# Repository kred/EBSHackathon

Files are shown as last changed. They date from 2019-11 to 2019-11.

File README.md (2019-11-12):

# EBSHackathon
Hackathon trophy model and firmware for Mentor Graphics Katowice hackathon event. Trophy is highly hackable!

## 3D model and 3D print
Trophy was designed in Autodesk Fusion 360. Step and stl models are located in the **Model** directory.
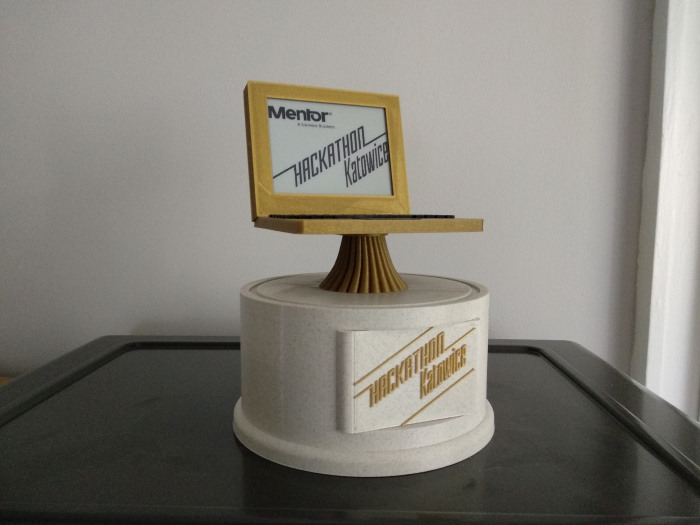
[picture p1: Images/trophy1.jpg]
Trophy

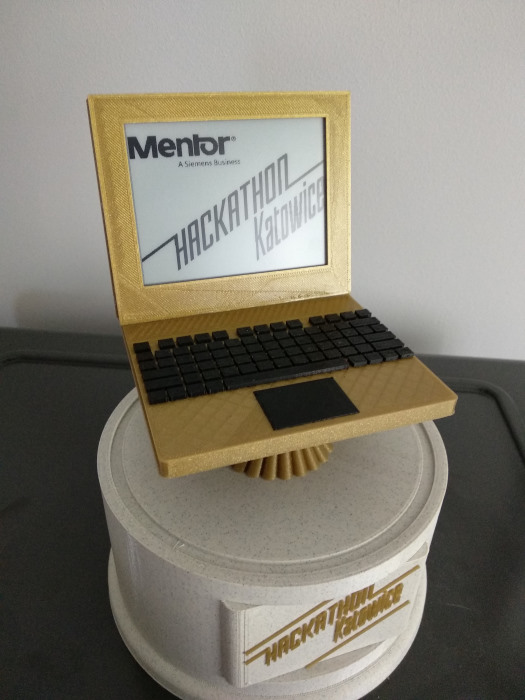
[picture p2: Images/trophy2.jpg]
Trophy

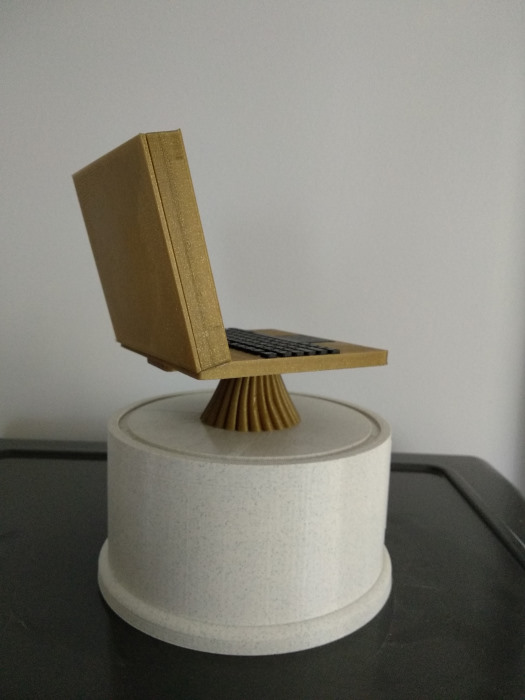
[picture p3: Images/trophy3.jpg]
Trophy

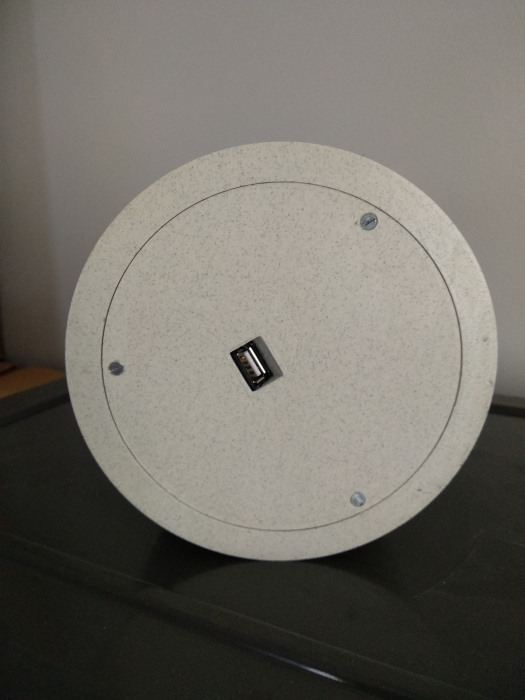
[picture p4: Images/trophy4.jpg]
Trophy


Front plate (where gold Hackathon Katowice label is shown) is detachable, so you may design new one and replace it. Notebook is glued to the foot and foot is connected to the base by three M3 screws. Notebook backplate is detachable, but currently is hot-glued to the display.
At the bottom of the base, there is circular cover fixed by three M3 screws. There is USB powerbank and ESP8266 inside. Power bank can be charged by external USB-A socket (power only - data signals are unconnected).

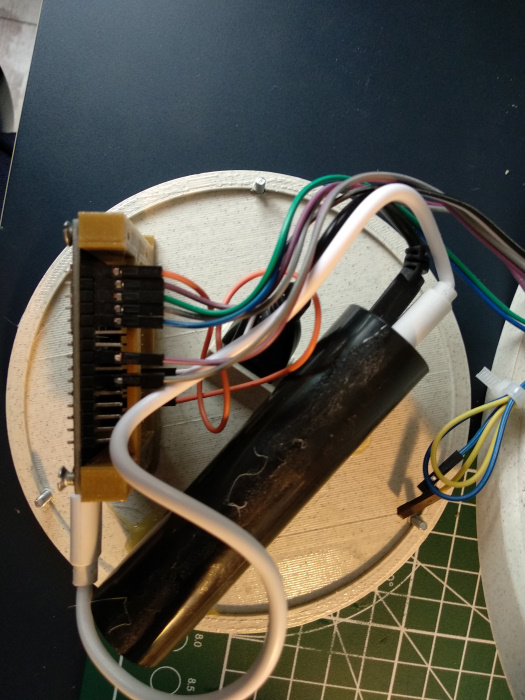
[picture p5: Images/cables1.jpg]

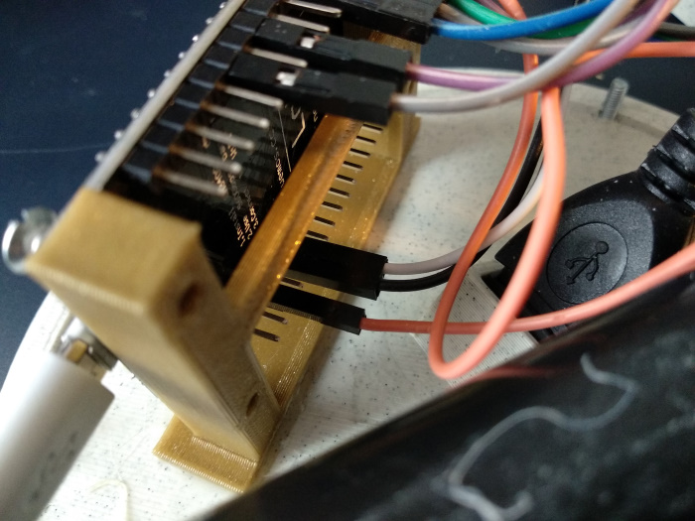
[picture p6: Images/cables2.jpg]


Due to the uncalibrated printer, trophy was printed around 2% smaller than designed - please account that difference when spare parts will be printed.

## Electronics
ESP8266 board is used - [Lolin D1 R2](https://botland.com.pl/pl/moduly-wifi/8241-modul-wifi-esp8266-nodemcu-v3.html) together with [Waveshare 4.2'' e-paper](https://botland.com.pl/pl/wyswietlacze-e-paper/9655-waveshare-e-paper-e-ink-42-400x300px-modul-z-wyswietlaczem-spi.html). Due to the deep-sleep functionality, D0 output is connected to the reset pin. There are two unconnected wires between base and monitor - can be used to e.g. power lights or connect some sensor.

## Firmware
Firmware is written in Arduino with ESP8266 support and GxEPD2 graphics library installed. These are only two packages needed to be installed to compile the firmware. WiFi is not used. ESP8266 is flexible, so you may install and use anything you need to hack the trophy.
To add new picture, prepare 400x300 black and white pixmap and convert it to C array using attached [BitmapConverter](https://github.com/briandorey/BitmapToByteArrayConverter). Example pixmaps are located in Firmware/images, converted arrays are located in Firmware/pic.h header.

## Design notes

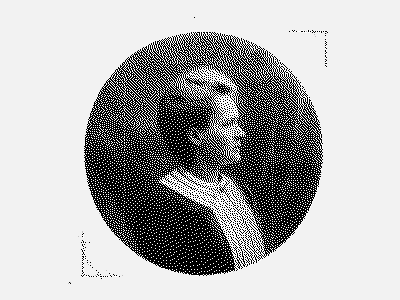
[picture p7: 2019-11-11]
Firmware/images/sklodowska.png

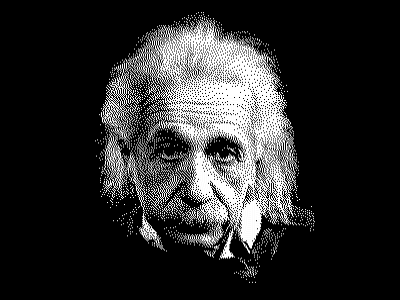
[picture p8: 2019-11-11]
Firmware/images/einstein.png

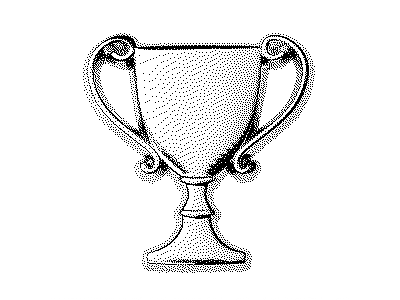
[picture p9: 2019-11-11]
Firmware/images/puchar.bmp

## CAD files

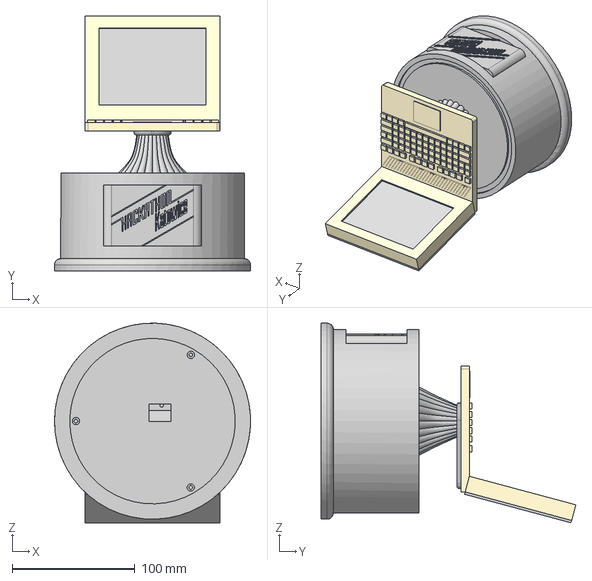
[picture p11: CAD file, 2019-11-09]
Model/hackathon trophy.step
160.0 x 207.9 x 162.9 mm
klawiatura
monitor

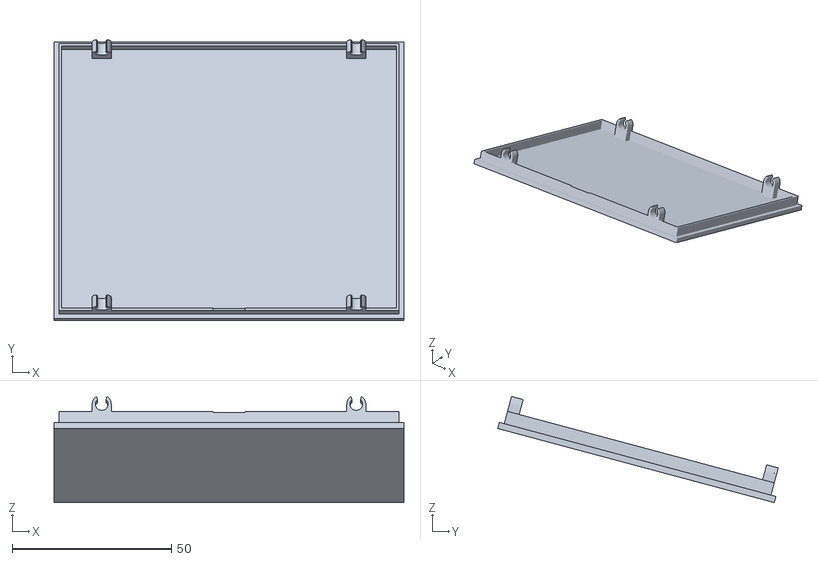
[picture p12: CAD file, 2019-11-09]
Model/monitor-plecy.stl
110.0 x 88.2 x 33.4

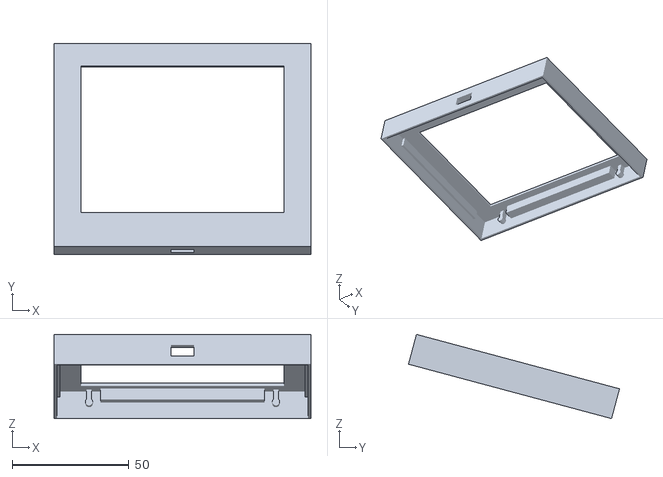
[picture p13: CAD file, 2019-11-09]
Model/monitor.stl
110.0 x 90.3 x 36.0

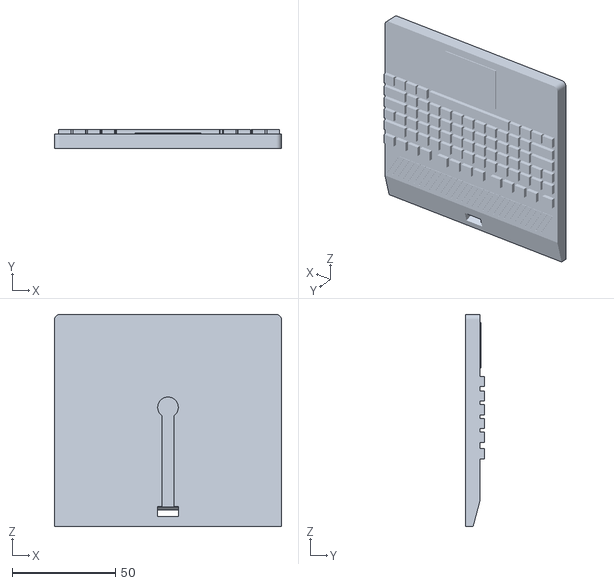
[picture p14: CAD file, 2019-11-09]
Model/klawiatura.stl
110.0 x 9.00 x 102.8

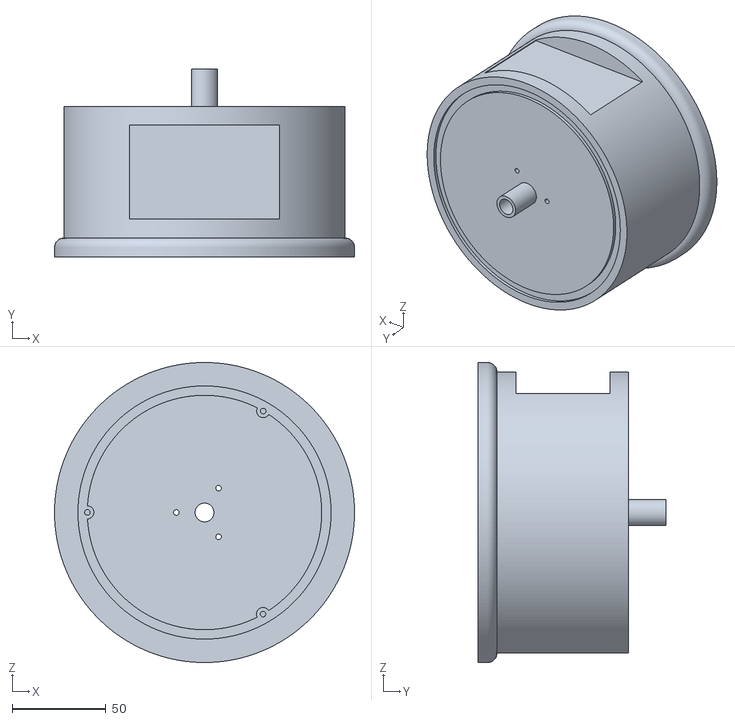
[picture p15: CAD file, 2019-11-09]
Model/podstawa.stl
160.0 x 100.0 x 160.0

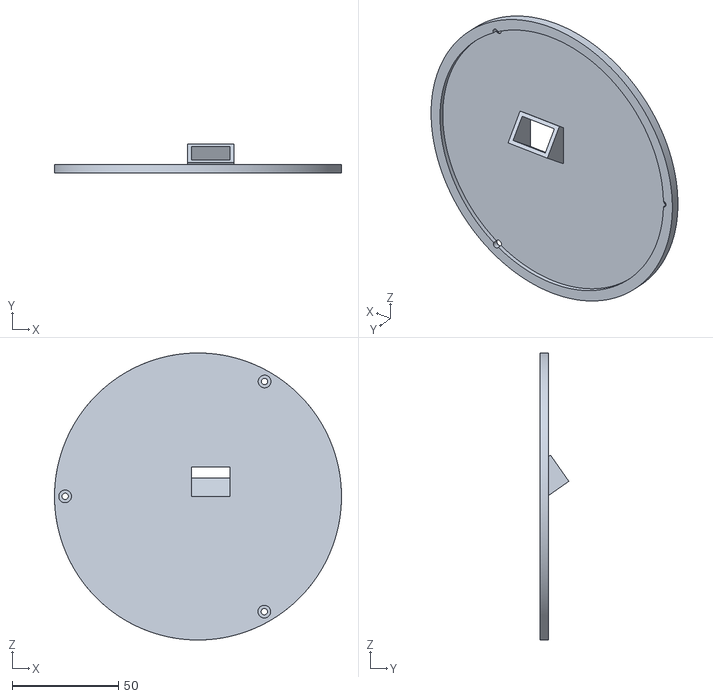
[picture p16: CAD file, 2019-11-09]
Model/zaslepka.stl
135.0 x 13.5 x 135.0

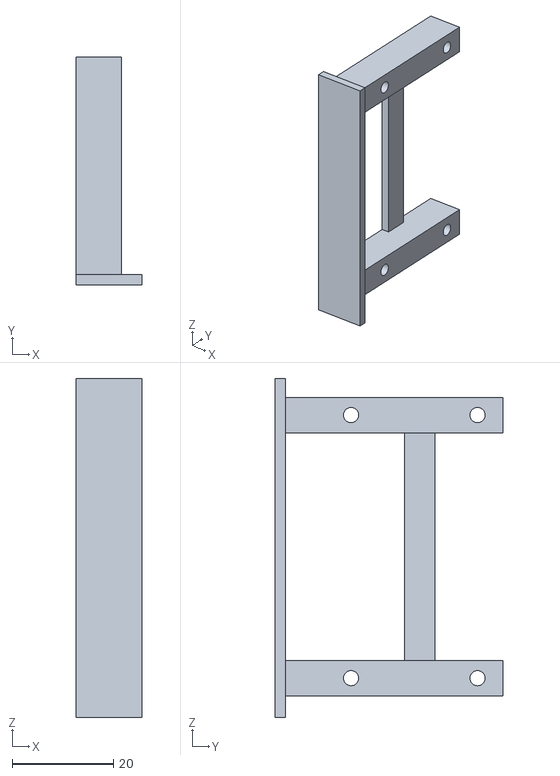
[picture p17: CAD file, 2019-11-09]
Model/esp8266.stl
13.0 x 45.0 x 67.0

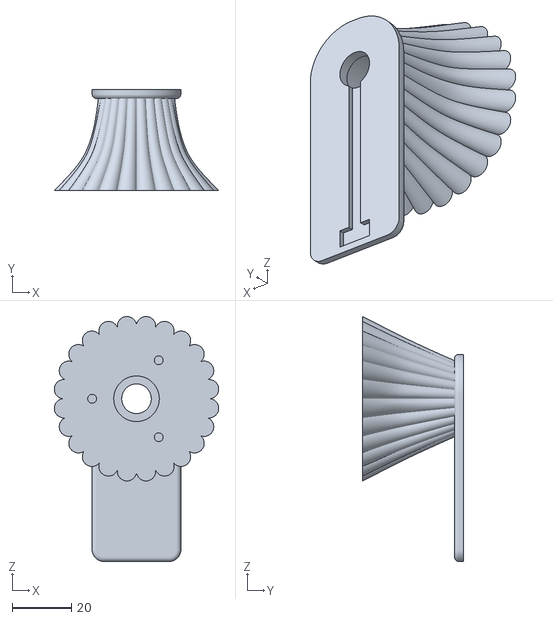
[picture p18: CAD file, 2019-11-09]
Model/mocowanie.stl
55.6 x 34.0 x 82.8

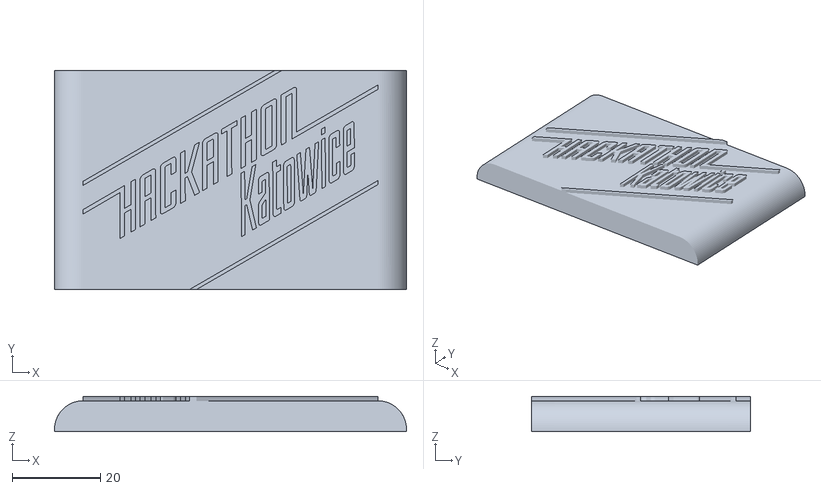
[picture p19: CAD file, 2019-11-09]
Model/plakietka.stl
80.0 x 49.8 x 8.00

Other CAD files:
Model/hackathon trophy.stl

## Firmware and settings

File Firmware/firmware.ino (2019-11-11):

#include <ESP8266WiFi.h>
#include <GxEPD2.h>
#include <GxEPD2_3C.h>
#include <GxEPD2_BW.h>
#include <GxEPD2_EPD.h>
#include <GxEPD2_GFX.h>

#include <Fonts/FreeMonoBold9pt7b.h>
#include "pic.h"

GxEPD2_BW<GxEPD2_420, GxEPD2_420::HEIGHT> display(GxEPD2_420(/*CS=D8*/ D3, /*DC=D3*/ D4, /*RST=D4*/ D1, /*BUSY=D2*/ D2));
const unsigned char* pics[] = {
  pic1,
  pic2,
  pic3,
  pic4
};

unsigned int updateCounter()
{
  unsigned int counter = 0;
  unsigned int newCounter = 0;
  unsigned int offset = 0;
  unsigned int newOffset = 0;
  const unsigned int OffsetAddress = 74;
  const unsigned int CounterAddress = 75;

  rst_info *resetInfo = ESP.getResetInfoPtr();
  if (resetInfo->reason != REASON_DEEP_SLEEP_AWAKE)
  {
    ESP.rtcUserMemoryWrite(OffsetAddress, &newOffset, sizeof(newOffset));
    
    for(int i = 0; i < 32; i++)
      ESP.rtcUserMemoryWrite(CounterAddress + i, &newCounter, sizeof(newCounter));

    return 0;
  }

  ESP.rtcUserMemoryRead(OffsetAddress, &offset, sizeof(offset));
  newOffset = offset;
    
  ESP.rtcUserMemoryRead(CounterAddress + offset, &counter, sizeof(counter));
  if (counter == 255)
  {
    counter = 0;
    newOffset = offset + 1;
    if (newOffset == 32)
    {
      ESP.rtcUserMemoryWrite(CounterAddress + offset, &counter, sizeof(counter));
      newOffset = 0;
    }
  }
  newCounter = counter + 1;
  if (newOffset != offset)
    ESP.rtcUserMemoryWrite(OffsetAddress, &newOffset, sizeof(newOffset));
    
  ESP.rtcUserMemoryWrite(CounterAddress + newOffset, &newCounter, sizeof(newCounter));

  return counter;
}

void setup() {
  
  display.init(115200);
  display.setRotation(0);
  display.setFont(&FreeMonoBold9pt7b);
  display.setFullWindow();
}

void loop() {
  unsigned int picNo = updateCounter() % 4;
 
  display.firstPage();
  do
  {
    display.fillScreen(GxEPD_WHITE);
    display.drawInvertedBitmap(0, 0, pics[picNo], display.epd2.WIDTH, display.epd2.HEIGHT, GxEPD_BLACK);
  }
  while (display.nextPage());
  display.hibernate();

  ESP.deepSleep(45e6); // 45s deep sleep

}

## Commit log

2019-11-09 Upload STL files of Hackathon trophy
    [esp8266.stl, hackathon trophy.stl, klawiatura.stl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]
2019-11-09 Upload STEP model of Hackathon trophy
    [hackathon trophy.step]
2019-11-11 Rename arduino sketch
